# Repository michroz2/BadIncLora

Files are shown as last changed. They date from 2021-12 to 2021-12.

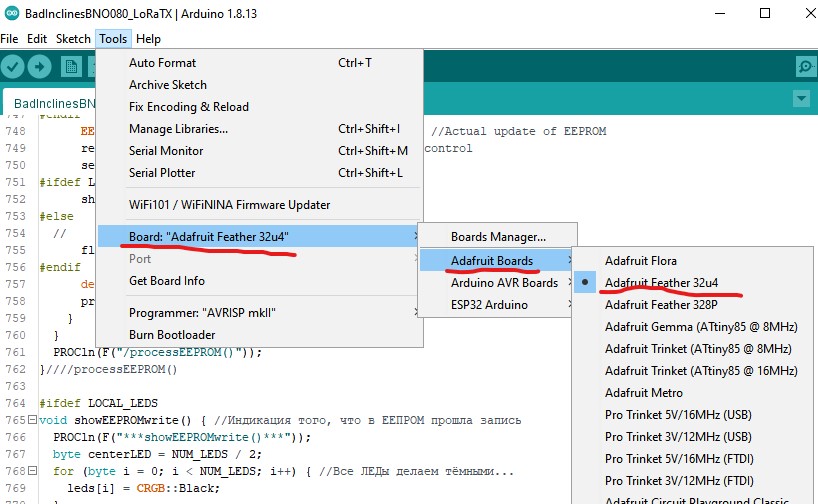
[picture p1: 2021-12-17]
Board selection for BSFrance.jpg

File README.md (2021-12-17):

BadIncLora - 
Уровень на основе BNO080, с передачей данных по LoRa на модуль индикации
TX/RX выполнены на BSFrance LoRa32u4
индикатор - светодиодная лента WS2812B
Файлы:
BadInclinesBNO080_LoRaRX/BadInclinesBNO080_LoRaRX.ino - Ардуино код приёмника
BadInclinesBNO080_LoRaTX/BadInclinesBNO080_LoRaTX.ino - Ардуино код сенсора и передатчика
BadIncLoraRX.fzz - Фритцин проект приёмника
BadIncLoraTX.fzz - Фритцин проект передатчика
BadIncLoraRX_bb.png - картинка соединений приёмника
BadIncLoraTX_bb.png - картинка соединений передатчика
README.md - этот файл
Arduino-Files-Preferences-Additional....jpg - URL для добавления Адафрутовских контроллеров (потом перегрузить Ардуино)
Board selection for BSFrance.jpg - какой микроконтроллер выбирать при прошивке

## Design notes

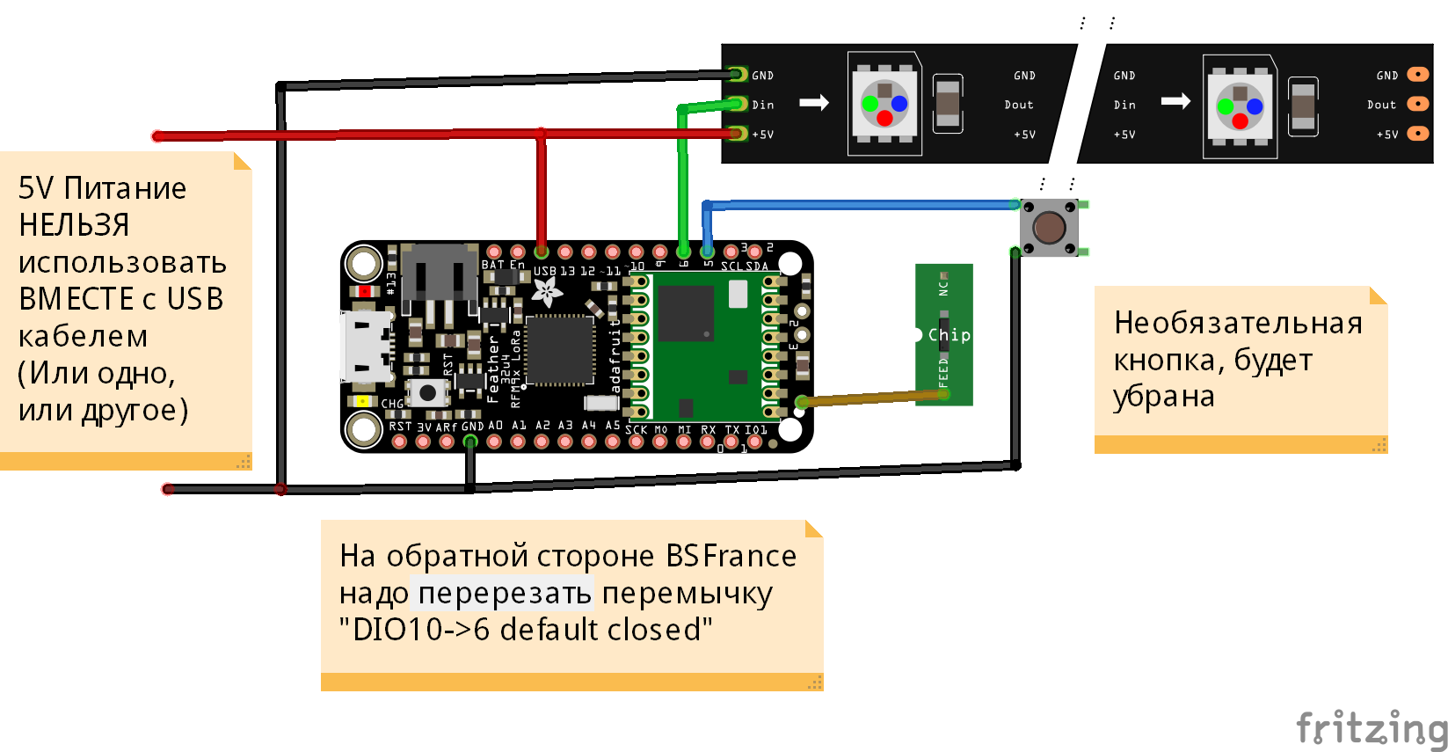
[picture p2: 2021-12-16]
BadIncLoraRX_bb.png

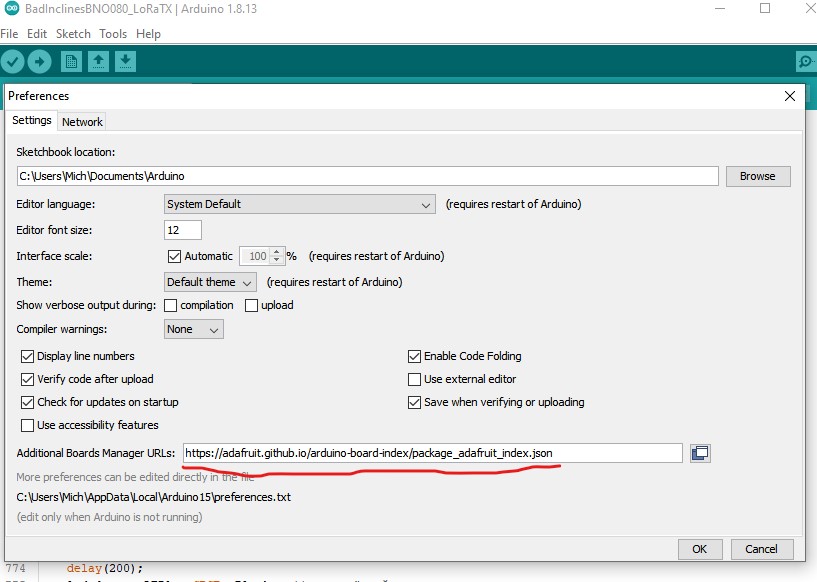
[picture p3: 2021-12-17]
Arduino-Files-Preferences-Additional....jpg

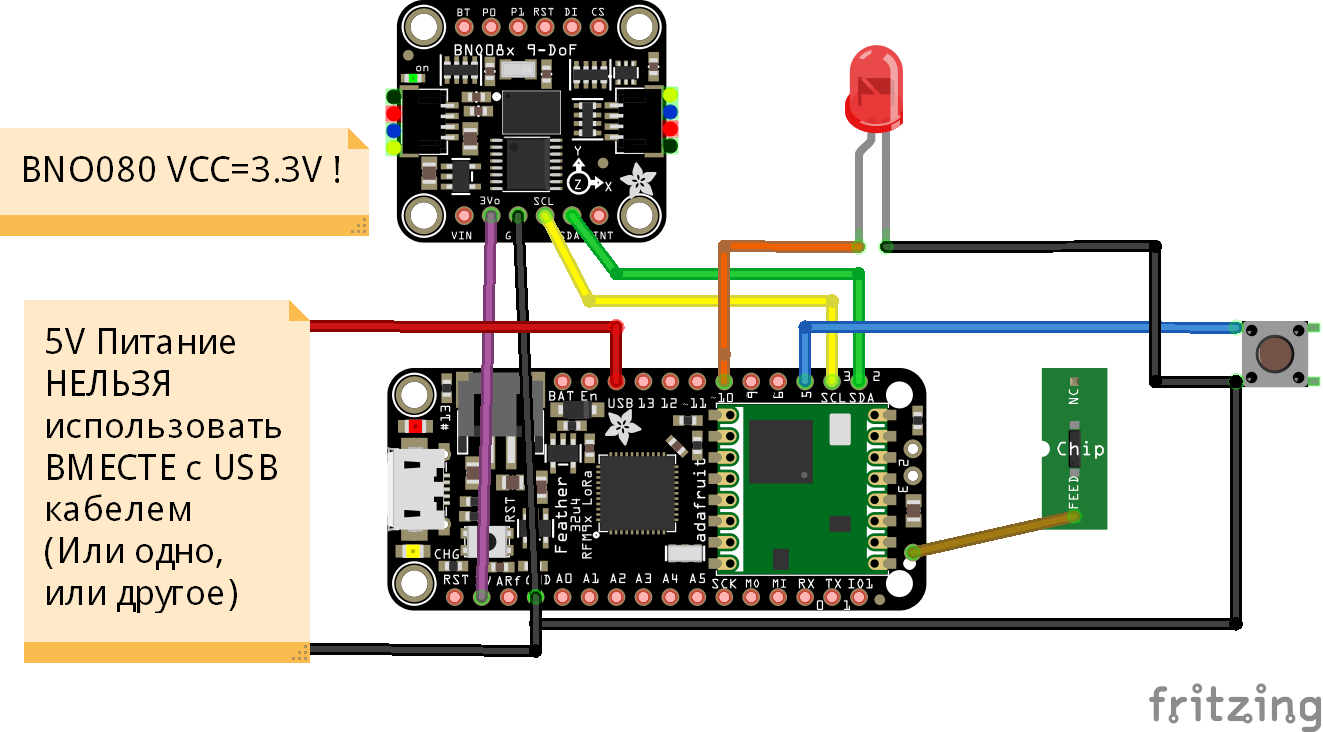
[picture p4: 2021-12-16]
BadIncLoraTX_bb.png

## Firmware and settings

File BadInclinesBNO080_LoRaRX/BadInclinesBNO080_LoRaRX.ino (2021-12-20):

/* Version 1.1
 *  Log:

  16.11.2021  Запустить на BSFrance (не используя пока Лору) - DONE
  21.11.2021 Скопировать в LoRaRX - DONE
  15.12.2021 очищено от лишнего кода (кроме кнопки) и загрузить в приёмник - DONE
  15.12.2021 Обработка полученного ЛоРа сигнала - DONE
  21.12.2021 Вернуть код ЕПРОМа для записи яркости и реверса
  21.12.2021 Делается запись в местный ЕЕПРОМ между 1 и 2 морганием светодиода записи 
  
  ===============
  Цель проекта: инерционно-независимый уровень.
  Соединяем IMU BNO080 и светодиодную ленту WS2812B в одном приборе!
  Разнести датчик и индикатор и соединить их по радио через LoRa

  ===============
  Соединения:
    Лента WS2812B 13 светодиодов (задаётся в коде - в принципе любое, из-за среднего "нуля" напрашивается нечётное число):
      +5v -> 5v BSFrance LoRa32u4
      GND -> GND BSFrance LoRa32u4
      DIN (сигнал) -> D6 BSFrance LoRa32u4 (настраивается в коде)
      NOTE!!! На обратной стороне BSFrance надо перерезать перемычку "DIO10->6 default closed"
    Control button "NO"(нормально-открытые) контакты:
  (В принципе, кнопка не нужна на приёмнике; используется для проверки работы при отладке)
      1 -> GND
      2 -> D5 BSFrance LoRa32u4 (задаётся в коде)
  Функции кнопки:
    Короткое нажатие: Яркость (следующее в соответствующем списке значение глобальной яркости индикатора)
    Двойное нажатие: Чувствительность (следующая настройка чувствительности)
    Длинное нажатие (более короткое): Обнуление датчика;
    Длинное нажатие (очень длинное): Инверсия сторон индикатора
*/
//Поиск мест, где можно что-то менять - по ключевому слову: ПОДСТРОЙКА

#include <FastLED.h> //для ленты WS2812B
#include <OneButton.h> //для кнопки
#include <EEPROM.h> //для сохранения настроек прибора в памяти EEPROM между включениями
#include <SPI.h>              // include LoRa required 2 libraries
#include <LoRa.h>

//ПОДСТРОЙКА: Дебагирование (вывод текстов на Serial Monitor): раскомментить следующую 1 строчку:
//#define DEBUG_ENABLE  //ЗАКОММЕНТИРОВАТЬ, когда всё отработано, перед окончательной загрузкой на BSFrance LoRa32u4
#ifdef DEBUG_ENABLE
#define DEBUG(x) Serial.print(x)
#define DEBUGln(x) Serial.println(x)
#else
#define DEBUG(x)
#define DEBUGln(x)
#endif

#ifdef DEBUG_ENABLE
#define TODO(x) Serial.print(F("TODO:\t")); Serial.println(F("x"))
#else
#define TODO(x)
#endif

//#define PROC_ENABLE  //вывод на монитор входы-выходы функций. ЗАКОММЕНТИРОВАТЬ, когда отработаны последовательности переходов процедур
#ifdef PROC_ENABLE
#define PROC(x) Serial.print(x)
#define PROCln(x) Serial.println(x)
#else
#define PROC(x)
#define PROCln(x)
#endif

//Настройки для ленты:
#define PIN_LEDS 6    //К какому дигитальному пину подключено управление ЛЕДами
#define NUM_LEDS 13   //количество ЛЕДов в ленте
#define NUM_MODES 23  //Количество вариантов свечения ленты

// PIN для кнопки:
#define PIN_CONTROL_BUTTON 5 //Button PIN (а второй NO вывод кнопки ->GND)

//Дефолтовые: 10, 9, 2 для SPI библиотеки (которая используется для связи с LoRa)
const int csPin = 8;          // LoRa radio chip select AdaFruit/BSFrance
const int resetPin = 4;       // LoRa radio reset AdaFruit/BSFrance
const int irqPin = 7;         // change for your board; must be a hardware interrupt pin AdaFruit/BSFrance

//ПОДСТРОЙКА синхронно для TX и RX в диапазоне 0-254, а также чтобы не совпадало с другими лорами
byte workAddress = 111;  // address of connection

//ПОДСТРОЙКА частоты - должна совпадать у TX и RX и желательно отличаться от других систем, хотя бы на 1E5 (100КГц)
unsigned long workFrequency = 4345E5; //working Frequency: 434.5MHz

//Команды для связи:
#define CMD_BRIGHTNESS       100 //параметр = номер яркости в списке fades
#define CMD_SENSITIVITY      101 //параметр = curSensitivity 
#define CMD_SWITCHSIDES      102 //параметр = revers 
#define CMD_LONGPRESS        103 //параметр = 1
#define CMD_CALIBRATION      104 //параметр = 1
#define CMD_MODE             111 //параметр = curMode от 0 до NUM_MODES
#define CMD_GREETING         112 //параметр = whatever?
#define CMD_EEPROM_WRITE     113 //параметр = whatever?

//Это «рабочий» массив для ленты: заполняем его нужными цветами и вызываем show
CRGB leds [NUM_LEDS];

//ПОДСТРОЙКА: Здесь можно исправлять вручную паттерны ЛЕДов для отколонений влево.
// (паттерны для уклонов вправо задавать не надо - они получатся симметрично автоматически)
CRGB modes[NUM_MODES][NUM_LEDS] =
  //LED_FULL_BRIGHTNESS
{
  {0xff0000, 0x640800, 0x321400,        0,        0,        0,        0,        0, 0, 0, 0, 0, 0},  //L11
  {0xff0000, 0x8c0000, 0x500a00, 0x3c1400, 0x200800,        0,        0,        0, 0, 0, 0, 0, 0},  //L10
  {0xff0000, 0x780000, 0x641000, 0x321E00, 0x180E00, 0x0F1400, 0x000400,        0, 0, 0, 0, 0, 0},  //L9
  {0x0a0000, 0x780000, 0x641000, 0x321E00, 0x321E00, 0x1E2D00, 0x000C00,        0, 0, 0, 0, 0, 0},  //L8
  {0x040000, 0x080000, 0x641000, 0x501E00, 0x463200, 0x283C00, 0x001E00,        0, 0, 0, 0, 0, 0},  //L7
  {0,        0x040000, 0x080000, 0x501E00, 0x5A4600, 0x3C5000, 0x003200,        0, 0, 0, 0, 0, 0},  //L6
  {0,        0,        0x040000, 0x501E00, 0x786400, 0x506400, 0x005000,        0, 0, 0, 0, 0, 0},  //L5
  {0,        0,        0,        0x321E00, 0x786400, 0x647800, 0x007800,        0, 0, 0, 0, 0, 0},  //L4
  {0,        0,        0,        0,        0x786400, 0x647800, 0x00A000,        0, 0, 0, 0, 0, 0},  //L3
  {0,        0,        0,        0,        0x2D1E00, 0x647800, 0x00C800,        0, 0, 0, 0, 0, 0},  //L2
  {0,        0,        0,        0,        0,        0x467800, 0x00FF00,        0, 0, 0, 0, 0, 0},  //L1
  {0,        0,        0,        0,        0,        0x002020, 0x00FF00, 0x002020, 0, 0, 0, 0, 0},  //!LEVEL MODE!
};

//ПОДСТРОЙКА: здесь можно задавать яркости:
#define NUM_FADES 4   //Количество вариантов яркости ленты
uint8_t fades [NUM_FADES] = {255, 64, 32, 8}; //значение яркости при каждом варианте (255 = макс)

//Следующий паттерн («двойная радуга») загорится при длинном нажатии кнопки.
//При отпускании сразу после «радуги» вся лента загорится синим и пойдёт процесс обнуления.
CRGB modeLongPressStart [NUM_LEDS] =
{
  CRGB::Red, CRGB::Orange, CRGB::Yellow, CRGB::Green, CRGB::Blue, CRGB::Indigo, CRGB::Violet,
  CRGB::Indigo, CRGB::Blue, CRGB::Green, CRGB::Yellow, CRGB::Orange, CRGB::Red
};

//(Возможна ПОДСТРОЙКА :)
//Это паттерн  приветствия
//Последовательно пробежит, заполняясь слева направо от края до края,
//вот такое количество таких цветов:
#define NUM_TEST_COLORS 3
CRGB testColors [NUM_TEST_COLORS] =
{  CRGB::Red, CRGB::Green, CRGB::Blue };

//ПОДСТРОЙКА времени (в целых секундах), после которого LEDы уйдут в StandBy
unsigned long StandByTime = 30;
unsigned long nextStandByMillis;

//Define Control Button.
OneButton buttonControl(PIN_CONTROL_BUTTON, true);

byte curFade; //Текущее значение яркости
byte curMode;   //Новое значение режима (зависит от угла наклона)
byte prevMode = -1; //Предыдущее значение режима
//float Roll;   //Крен, который и надо показать светодиодами
//float deltaZero; //Поправка на неровность установки
boolean revers;   //Переключалка для сторон уровня

#define MAX_INDEX 8
byte rcvCmd[MAX_INDEX];      //Полученная команда
byte rcvData[MAX_INDEX];     //Полученный параметр комады
byte rcvIndex, curIndex;    //Позиция получаемой и выполняемой команды в кольцевом стеке
boolean StandBy;            //Индикатор того, что приёмник в режиме стэндбай

#define NUM_SENSITIVITIES 4                         //ПОДСТРОЙКА количества вариантов чувствительности

byte curSensitivity = 0;    //Текущее значение чувствительности, для начала 0

#define VERY_LONG_PRESS_MS  3000  //это ПОДСТРОЙКА: длительность очень длинного нажатия (мс), при котором
//вместо калибровки произойдёт инверсия сторон индикатора

boolean startCalibrationMode = false;
uint32_t verylongPressTimer = 0;

//EEPROM things
#define WRITE_EEPROM_DELAY_MS   15000   //ПОДСТРОЙКА: задержка между последним изменением параметров и 
//сохранением их в ЕЕПРОМ. (Если за это время произвести новое изменение параметров, то сохранение отложится ещё на такое же время. )
#define EEPROM_OLD_CODE 254  // - специальный код для распознавания нужного места для чтения/записи ЕЕПРОМ

struct RX_EEPROMData { //Структура для чтения и записи данных EEPROM  - 4 байта
  byte code;  // = 254
  byte state; // = по битам: 0|FFF|SSS|R = Fade|Sensitivity|Reverse (это никогда не равно 254, то есть не может быть спутано с кодом при чтении)
  //  int deltaLSD;  // = deltaZero * 16 - Это по спеку датчика BNO080 должно быть целое число в единицах LSD
  //  //Для экономии места EEPROM, угол поправки записывается в виде целого числа = угол * 16 (округлённо)
  // (Для приёмника не требуется запоминать дельту датчика!)
};

RX_EEPROMData readRX_EEPROMData;
RX_EEPROMData writeRX_EEPROMData;
boolean    writeEEPROM = false;
uint32_t    writeEEPROMtimer = 0;

//ПОДСТРОЙКА: Setting defaults for EEPROM values:
#define EEPROM_WRITE_BLINK_DELAY 200  //milliseconds
byte defaultFade = 0;
byte defaultSensitivity = 0;
boolean defaultrevers = false;

//Переменные для хранения последних прочитанных данных
int lastEEPROMAddress = 0;
byte readFade;
byte readSensitivity;
boolean readrevers;
int writesEEPROM = 0;   //Number of EEPROM writes in this session
int static maxWrites = 10;  //After this number of writes in one session, we shift the EEPROM address by 1 to prevent wear (?)
unsigned long nextEEPROMwriteblink;

//****************************************************************************************************
void setup() { //===========  SETUP =============

  // initialize serial port to output the debug information (if necessary)
#ifdef DEBUG_ENABLE
  Serial.begin(9600);
  while (!Serial);
#endif

  DEBUGln(F("Bad Inclines LoRa RX ==== Setup ===="));

  initButtons();  //времено оставлено для отладки
  initMODS();
  readEEPROM();
  initLEDs();
  initLoRa();
  playGreeting();
  StandByTime = StandByTime * 1000; //тупо превращаем секунды в миллисекунды
  nextStandByMillis = millis() + StandByTime;       //и устанавливаем следующее время стендбая
}

void loop() {  //===========  LOOP =============
  PROCln(F("tick()"));
  buttonControl.tick();   // keep watching the push button
  PROCln(F("/tick()"));
  processCommand();
  processLEDS();          //Обновляем (если надо) паттерн свечения светодиодов
}              //=========== /LOOP =============

void initButtons() {
  PROCln(F("initButtons()"));
  // link the CONTROL button functions.
  buttonControl.attachClick(clickControl);
  delay(20);
  buttonControl.attachDoubleClick(doubleclickControl);
  delay(20);
  buttonControl.attachLongPressStart(longPressStartControl);
  delay(20);
  buttonControl.attachLongPressStop(longPressStopControl);
  delay(20);
  buttonControl.attachDuringLongPress(longPressControl);
  delay(20);
}////initButtons()

void clickControl() {
  PROCln(F("Control Button clicked"));
  DEBUGln(F("Fade Function"));
  curFade = (curFade + 1) % NUM_FADES;
  // set master brightness control
  showBrightness();

  DEBUG(F("Current Brightness Number: "));
  DEBUG(curFade);
  DEBUG(F(",\tCurrent Brightness: "));
  DEBUGln(fades[curFade]);
}////clickControl()

void showBrightness() {
  FastLED.setBrightness(fades[curFade]);
  prevMode = -1;    //Делаем искусственно так, чтобы индикатор обновился, даже если не изменился угол
}////showBrightness();

void doubleclickControl() {
  PROCln(F("Control Button double-clicked"));
  curSensitivity = (curSensitivity + 1) % NUM_SENSITIVITIES;
  showSensitivity();
}////doubleclickControl()

void showSensitivity() {
  PROCln(F("showSensitivity()"));
  for (byte i = 0; i < NUM_LEDS; i++) {
    leds[i] = 0;
  }
  leds[curSensitivity] = modeLongPressStart[curSensitivity];
  leds[NUM_LEDS - curSensitivity - 1] = modeLongPressStart[curSensitivity];
  FastLED.show();
  delay(1000);
  prevMode = -1;
  DEBUG(F("Sensitivity: "));
  DEBUGln(curSensitivity);

}////showSensitivity()


void switchSides() {
  DEBUG(F("Switching the sides: "));
  revers = !revers;
  DEBUGln(revers);
  showSwitchSides();
  copyMode();
  prevMode = -1;
}////switchSides()

void showSwitchSides() {
  for (byte i = 0; i < NUM_LEDS / 2; i++) {
    leds[i] = CRGB::Blue;
    leds[NUM_LEDS - i - 1] = CRGB::Red;
    FastLED.show();
  }
  delay(1000);
  for (byte i = 0; i < NUM_LEDS / 2; i++) {
    leds[i] = CRGB::Red;
    leds[NUM_LEDS - i - 1] = CRGB::Blue;
  }
  FastLED.show();
  delay(1000);

}////showSwitchSides()


void longPressStartControl() {
  PROCln(F("Control Button long-press started"));
  startCalibrationMode = true;  //if release button soon, then start calibration
  verylongPressTimer = millis() + VERY_LONG_PRESS_MS;  //start timer - для определения длины нажатия
  showLongPressStart();
}////longPressStartControl()

void showLongPressStart() {
  for (byte i = 0; i < NUM_LEDS; i++) {
    leds[i] = modeLongPressStart[i];
  }
  FastLED.show();
  delay(500);
}//showLongPressStart()

void longPressControl() {
  PROCln(F("Long Press Control Button ..."));
  if (millis() > verylongPressTimer) {
    DEBUGln(F("VERY Long Press detected..."));
    verylongPressTimer = millis() + VERY_LONG_PRESS_MS;  //start new timer - для следующего reverse
    startCalibrationMode = false;  //too long pressed for calibration
    switchSides();
  }
}////longPressControl()


void longPressStopControl() {
  PROCln(F("Control Button long-press stopped"));
  if (startCalibrationMode) {     //only if NOT VERY long pressed
    DEBUGln(F("Starting Calibration!"));
    startCalibrationMode = false;  //just in case, seems not necessary, but...
    showCalibration();
    prevMode = -1;
  }
}////longPressStopControl()

void showCalibration() {
  for (byte i = 0; i < NUM_LEDS; i++) {
    leds[i] = CRGB::Blue;  //set Blue lights to indicate calibration
  }
  FastLED.show();
  delay(500);
}////showCalibration()



void initMODS() { //Симетрично инициализируем значения массивов ледов для отклонения вправо
  PROCln(F("initMODS()"));

  curMode = NUM_MODES / 2;  // это будет центр, то есть «LEVEL» и с него мы начнём работу
  prevMode = -1;

  for (byte i = 0; i < NUM_MODES / 2; i++) {
    for (byte j = 0; j < NUM_LEDS; j++) {
      modes[NUM_MODES - i - 1][NUM_LEDS - j - 1] = modes[i][j];
      delay(10);
    }
  }
  //Контроль правильности присвоения всем модам и всем яркостям:
#ifdef DEBUG_ENABLE
  Serial.println(F("Modes:")); //заголовок
  for (byte i = 0; i < NUM_MODES; i++) {
    for (byte j = 0; j < NUM_LEDS; j++) {
      for (byte k = 0; k < 2; k++) {
        Serial.print(String(modes[i][j][k]) + ("/")); //значения R и G единичных ледов
      }
      Serial.print(String(modes[i][j][2])); //значениe Blue единичного леда
      Serial.print(F("\t")); //разделитель отдельных значений одной моды
    }
    Serial.println();   //перевод строки - разделитель мод
  }
  Serial.println(F("------------------"));   //конец вывода мод
#endif

}////initMODS()

void copyMode() {
  byte k;
  for (byte i = 0; i < NUM_LEDS; i++) {
    k = revers ? (NUM_LEDS - 1 - i) : i;
    leds[i] = modes[curMode][k] ;
  }

}////copyMode()

void processLEDS()  {
  PROCln(F("processLEDS()"));
  if (curMode != prevMode) //
  {
    copyMode();
    FastLED.show();
    prevMode = curMode;
  }
  PROCln(F("/processLEDS()"));
}  ////processLEDS()

void  initLEDs()  { //Инициализация индикаторной ленты
  PROCln(F("initLEDs()"));

  pinMode(PIN_LEDS, OUTPUT);

  FastLED.addLeds<WS2812B, PIN_LEDS, GRB>(leds, NUM_LEDS);
  delay(100);
  FastLED.setBrightness(fades[curFade]);
  delay(100);
}////initLEDs()

void playGreeting() {
  PROCln(F("«««««playGreeting()»»»»»"));
  for (byte j = 0; j < 3; j++) {
    for (byte i = 0; i < NUM_LEDS; i++) {
      leds[i] = testColors[j];
      delay(10);
      FastLED.show();
      delay(40);   //ПОДСТРОЙКА
    }
    prevMode = -1;    //Делаем искусственно так, чтобы индикатор обновился
    delay(100);
  }
}////playGreeting();

void readEEPROM() {
  DEBUGln(F("Reading from EEPROM"));
  lastEEPROMAddress = 0;
  byte value;
  //Находим по коду положение предыдущей, последней записи в ЕЕПРОМ
  //(Это там, где обрываются записи 254,254,254...)
  for (int i = 0; i < (EEPROM.length() - sizeof(RX_EEPROMData)); i++) {
    value = EEPROM.read(i);
    delay(100);
    if (value != EEPROM_OLD_CODE ) {
      lastEEPROMAddress = i;
      break;
    }
  }
  //Если здесь будет lastEEPROMAddress == 0, то в ЕЕПРОМе не найдена запись предыдущих параметров
  if (lastEEPROMAddress == 0) {
    DEBUGln(F("Setting defaults!!!"));
    curFade = defaultFade;
    curSensitivity = defaultSensitivity;
    revers = defaultrevers;
    readFade = defaultFade;
    readSensitivity = defaultSensitivity;
    readrevers = defaultrevers;

    return;   //exit from function
  };
  //Here the address is > 0!
  lastEEPROMAddress = lastEEPROMAddress - 1;
  DEBUG(F("EEPROM Data found at position: "));
  DEBUGln(lastEEPROMAddress);

  EEPROM.get(lastEEPROMAddress, readRX_EEPROMData);
  delay(100);
  uncodeRX_EEPROMData();

  curFade = readFade;
  curSensitivity = readSensitivity;
  revers = readrevers;

#ifdef DEBUG_ENABLE
  printRX_EEPROMData();
#endif
}////readEEPROM()

void   codeRX_EEPROMData() { //Кодирует записываемые данные во writeRX_EEPROMData
  writeRX_EEPROMData.code = EEPROM_OLD_CODE;
  writeRX_EEPROMData.state = byte(revers) | curSensitivity << 1 | curFade << 4;
}/////codeRX_EEPROMData()

void uncodeRX_EEPROMData() {   //ДЕ-кодирует записываемые данные из readRX_EEPROMData
  readFade = (readRX_EEPROMData.state & B01110000) >> 4;
  readrevers = (readRX_EEPROMData.state & B00000001);
  readSensitivity = (readRX_EEPROMData.state & B00001110) >> 1;
}////uncodeRX_EEPROMData()

#ifdef DEBUG_ENABLE
void printRX_EEPROMData() {
  Serial.println("----------");
  Serial.print(F("Fade:\t"));
  Serial.println(  curFade);
  Serial.print(F("revers:\t"));
  Serial.println(  revers);
  Serial.print(F("Sensitivity:\t"));
  Serial.println(  curSensitivity);
  Serial.println("----------");
}////printRX_EEPROMData()
#endif

void processEEPROMwrite() {    //пишем в ЕЕПРОМ, когда приходит команда с  передатчика
  PROCln(F("processEEPROMwrite()"));
  startShowEEPROMwrite(); //начинаем показывать запись
  codeRX_EEPROMData();
  writesEEPROM = writesEEPROM + 1;
  DEBUG(F("Number of writes in this session: "));
  DEBUGln(writesEEPROM);
  if ((writesEEPROM % maxWrites) == 0) {
    DEBUGln(F("Shifting to the NEXT address!"));
    lastEEPROMAddress = (lastEEPROMAddress + 1) % (EEPROM.length() - sizeof(RX_EEPROMData) );
  }
#ifdef DEBUG_ENABLE
  DEBUGln(F("Before Writing to EEPROM at position:"));
  DEBUGln(lastEEPROMAddress);
  printRX_EEPROMData();
#endif
  // Производим запись:
  EEPROM.put(lastEEPROMAddress, writeRX_EEPROMData);   //Actual update of EEPROM
#ifdef DEBUG_ENABLE
  readEEPROM(); //read the written values back for control
  DEBUGln(F("Reading After Writing to EEPROM at position:"));
  DEBUGln(lastEEPROMAddress);
  printRX_EEPROMData();
#endif
  finishShowRXEEPROMwrite();
  prevMode = -1;    //Делаем так, чтобы индикатор обновился и картинка не зависла
  PROCln(F("/processEEPROM()"));
}////processEEPROMwrite()

void startShowEEPROMwrite() { //Включаем картинку, показывающую запись в ЕЕПРОМ
  PROCln(F("***startShowEEPROMwrite()***"));
  for (byte i = 0; i < NUM_LEDS; i++) { //Все ЛЕДы делаем тёмными...
    leds[i] = CRGB::Black;
  }
  leds[NUM_LEDS / 2] = CRGB::Red;  //...а центральный - красным,
  FastLED.show();
  nextEEPROMwriteblink = millis() + EEPROM_WRITE_BLINK_DELAY;
}////startShowEEPROMwrite()

void finishShowRXEEPROMwrite() { //Индикация того, что в RX ЕЕПРОМ прошла запись
  PROCln(F("***finishShowRXEEPROMwrite()***"));
  while (millis() < nextEEPROMwriteblink) {
    delay(5);
  } //wait ;
  leds[NUM_LEDS / 2] = CRGB::Black;  // потушить
  FastLED.show();
  delay(EEPROM_WRITE_BLINK_DELAY);

  for (byte j = 0; j < 2; j++) {
    leds[NUM_LEDS / 2] = CRGB::Red;  // зажечь
    FastLED.show();
    delay(EEPROM_WRITE_BLINK_DELAY);
    leds[NUM_LEDS / 2] = CRGB::Black;  // потушить
    FastLED.show();
    delay(EEPROM_WRITE_BLINK_DELAY);
  }
  prevMode = -1;    //Делаем так, чтобы индикатор обновился, даже если не изменился угол
}////showRXEEPROMwrite()

void showSwitchOff() { //Индикация перехода и переход LEDов в StandBy
  PROCln(F("***showSwitchOff()***"));
  byte centerLED = NUM_LEDS / 2;
  for (byte i = 0; i < NUM_LEDS; i++) { //Все ЛЕДы делаем тёмными...
    leds[i] = CRGB::Black;
  }
  for (byte j = 0; j < 3; j++) {
    leds[centerLED] = CRGB::Blue;  //...а центральный - то красный,
    FastLED.show();
    delay(200);
    leds[centerLED] = CRGB::Black;  //...то тёмный
    FastLED.show();
    delay(200);
  }
  delay(300);
}////showSwitchOff()

void showERROR() { //Индикация того, что в ЕЕПРОМ прошла запись
  PROCln(F("***showshowERROR()***"));
  byte centerLED = NUM_LEDS / 2;
  for (byte i = 0; i < NUM_LEDS; i++) { //Все ЛЕДы делаем тёмными...
    leds[i] = CRGB::Black;
  }
  for (byte j = 0; j < 5; j++) {
    leds[centerLED] = CRGB::Red;  //...а центральный - то красный,
    FastLED.show();
    delay(400);
    leds[centerLED] = CRGB::Black;  //...то тёмный
    FastLED.show();
    delay(400);
  }
}////showshowERROR()
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

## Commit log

2021-12-16 TX: sendAllData removed in processEEPROM() Added: Fritzing projects and PNG pictures
    [BadIncLoraRX.fzz, BadIncLoraTX.fzz]
2021-12-17 Добавлено 2 jpg файла по установке Адафрутовских микроконтроллеров и выбору нужного для BSFrance
    [BadIncLoraRX.fzz]
